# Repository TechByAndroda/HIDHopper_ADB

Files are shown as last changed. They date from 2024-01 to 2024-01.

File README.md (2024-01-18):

# HIDHopper ADB

HIDHopper ADB is a modified (forked) version of adbuino and QuokkADB.  It is a Raspberry Pi Pico based hardware device which converts USB keyboard and mouse inputs to the Apple Desktop Bus (ADB) standard.

# The Name
HIDHopper comes from the USB "HID" standard, for Human Interface Device.  Hopper just sounded right after HID.

# Picture
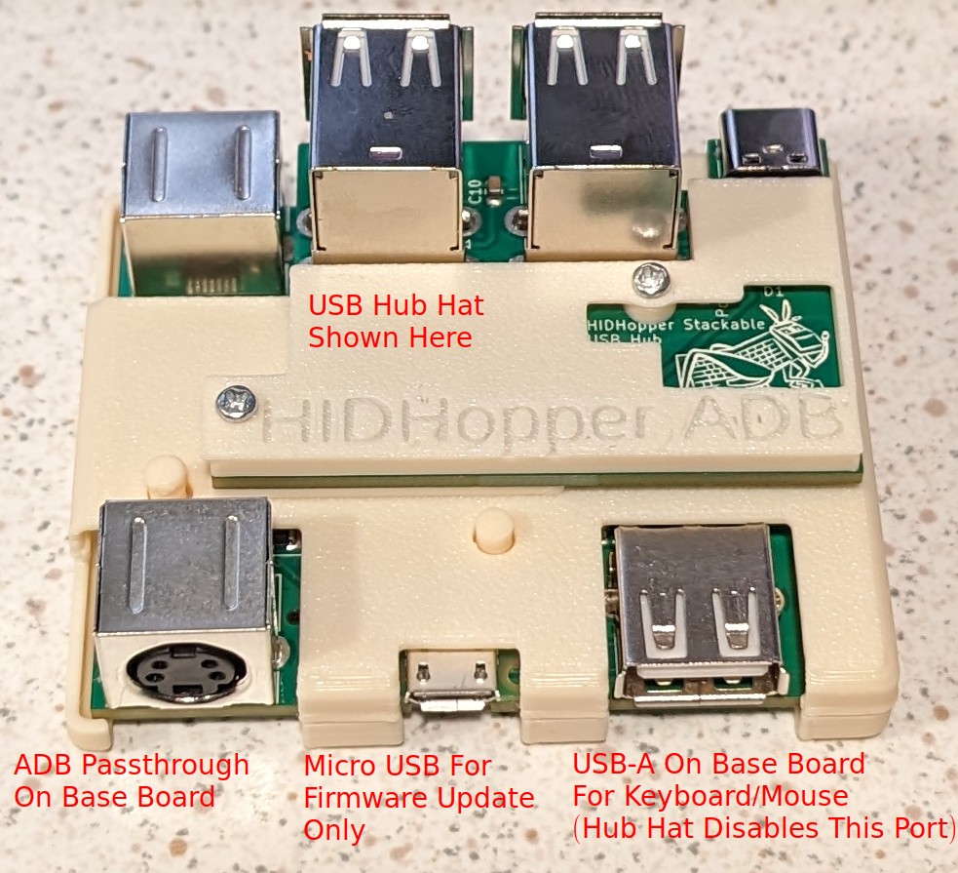
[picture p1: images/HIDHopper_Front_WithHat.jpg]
HIDHopper_ADB Hardware Image


# Usage
See the file [doc/HIDHopper.md](https://github.com/TechByAndroda/HIDHopper_ADB/blob/master/doc/HIDHopper.md) for more full documentation

# Quick Usage
- For Base HIDHopper without USB Hub, *before* turning on your computer:
   - Plug in your desired USB peripheral (keyboard or mouse)
   - Plug HIDHopper into the ADB bus
   - Start computer
   - Hot-plug *is not supported*, don't unplug from the ADB Bus *or* unplug the USB device that is connected while the computer is on
- For HIDHopper with the USB Hub Hat, *before* turning on your computer:
   - Ensure the Hub is solidly secured in place with the two mounting screws and top cover plate
   - Plug HIDHopper into the ADB bus
   - Plug in your external 5v USB-C power supply to the connector on the Hub
      - You *must use USB-C External Power* to avoid blowing the ADB Power fuse on your motherboard!
   - Plug in your desired USB keyboard and mouse
   - Hot-plug *is not supported*, don't unplug from the ADB Bus *or* unplug USB devices that are connected while the computer is on
      - Hot-plug of USB devices is finicky, sometimes it works and other times it does not
      - Best to connect before startup, that always works

# Background

This is a fork of Difegue's version of the [adbuino](https://github.com/Difegue/Chaotic-Realm), which was a modified version of [bbraun's](http://synack.net/svn/adbduino/) PS/2 to ADB arduino sketch, with some extra code added to alleviate issues with his own PS/2 keyboard.  For Difegue's original write-up, please read more info [here.](https://tvc-16.science/adbuino-ps2.html).

# How to build and flash HIDHopper ADB

Note: This software is intended to be compiled in an Ubuntu Linux environment.

- Install the Raspberry Pi Pico SDK (https://github.com/raspberrypi/pico-sdk)
- Set the `$PICO_SDK_PATH` environment variable to your pico-sdk directory
- Open a Terminal and "cd" into this project
- From the top level of this project, "cd" to the `src/firmware` folder
- In Terminal, execute the following commands from the above `src/firmware` folder:
  - `mkdir build`
  - `cd build`
  - `cmake ..`
  - `make`
- The build outputs (.uf2, .bin, .elf, etc) will be placed in this folder (path is from the top level of the project):
  - `src/firmware/build/src`
- Next, plug the micro-USB side of a USB cable into HIDHopper
- Press the button which is near the micro-USB port
- While holding down the button, plug the USB cable into your computer (then release the button after plugging in)
- You should see an "RPI-RP2" mass storage device appear on your computer
- Drag the ".uf2" file onto that mass storage device
- Once the mass storage device disappears, wait 10 seconds and then you are free to unplug

# References
ADB Pinout

## Protocol/Software Documentation
- [Apple ADB Manager Documenation](https://developer.apple.com/library/archive/documentation/mac/pdf/Devices/ADB_Manager.pdf)
- [ADB Overview](https://www.lopaciuk.eu/2021/03/26/apple-adb-protocol.html)
- [Microchip Application Note AN591](http://www.t-es-t.hu/download/microchip/an591b.pdf)
- [TMK Documentation](https://github.com/tmk/tmk_keyboard/wiki/Apple-Desktop-Bus)

## Other libraries
- [TinyUSB Library](https://github.com/raspberrypi/tinyusb)
- [MiSTER adb hardware emulation](https://github.com/mist-devel/plus_too/blob/master/adb.v)

## Development resources
- [Running OpenOCD without root](https://forgge.github.io/theCore/guides/running-openocd-without-sudo.html)

## Hardware Links
- [ADB Connector - mouser](https://www.mouser.com/ProductDetail/TE-Connectivity/5749181-1?qs=XlZqES4cpWbRcAMR%2FcJqkQ%3D%3D)

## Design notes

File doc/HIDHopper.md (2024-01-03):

# HIDHopper
A fork of adbuino / QuokkADB, HIDHopper ADB is a USB keyboard and mouse translator which converts USB signaling to Apple's vintage ADB standard.
This is for USB to ADB, and not currently the other way around.

## How to use
1. Attach any USB keyboards/mice to your HIDHopper ADB hardware
   * If you have the USB Hub Hat, EXTERNAL POWER MUST BE PROVIDED via the USB-C port!  Otherwise you run the risk of burning out the ADB Power fuse on your Mac's motherboard!
   * If you have the USB Hub Hat, only the Hat's USB ports work.  The USB port on the base device (by microUSB) will stop working to handle the hub connection.
   * The Hub Hat's USB-C Power must be un-plugged and plugged back in between each system start.  This is because certain parameters are set only on first ADB communication.
2. Ensure your HIDHopper device is plugged into your Mac before turning the computer on, and do not un-plug it (or plug it back in) while the system is running
3. The button by the ADB port on HIDHopper is the ADB Soft-Power button and can turn on systems which support that (Color Classic, PowerMac 7300, etc)
   * Systems which do not support ADB Soft-Power must be turned on with their respective physical switch
4. LEDs will turn on and blink with power and ADB activity
5. Again, DO NOT unplug HIDHopper from your Mac while it is turned on.  And DO NOT plug it into your Mac while it's turned on.  Only connect or disconnect while your Mac is turned off.

# Hardware

## Ports And Buttons

Every HIDHopper ADB device comes with:
* Two ADB ports, allowing daisy-chaining
* One USB-A port for keyboard/mouse (This port is disabled if you are using the Hub Hat)
* One micro-USB port (for firmware upgrades)
* One 4-pin jumper header for the USB Hub Hat
* An ADB Soft Power-on Button
* A button for use in entering Firmware Update mode

HIDHopper ADB Front Picture
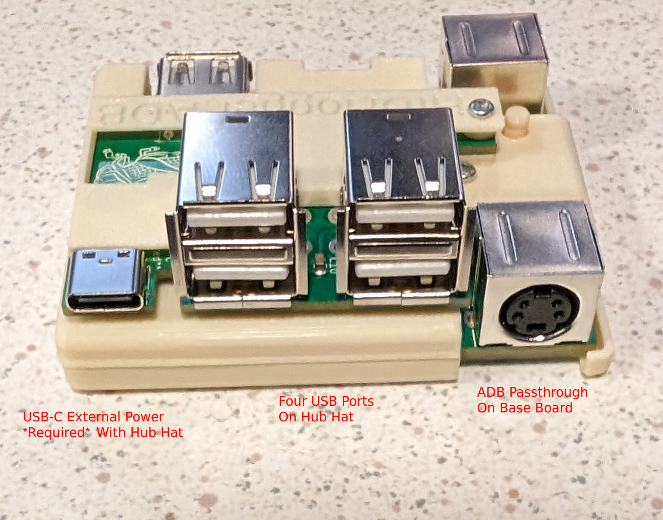
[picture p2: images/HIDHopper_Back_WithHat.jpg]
HIDHopper ADB Back Picture

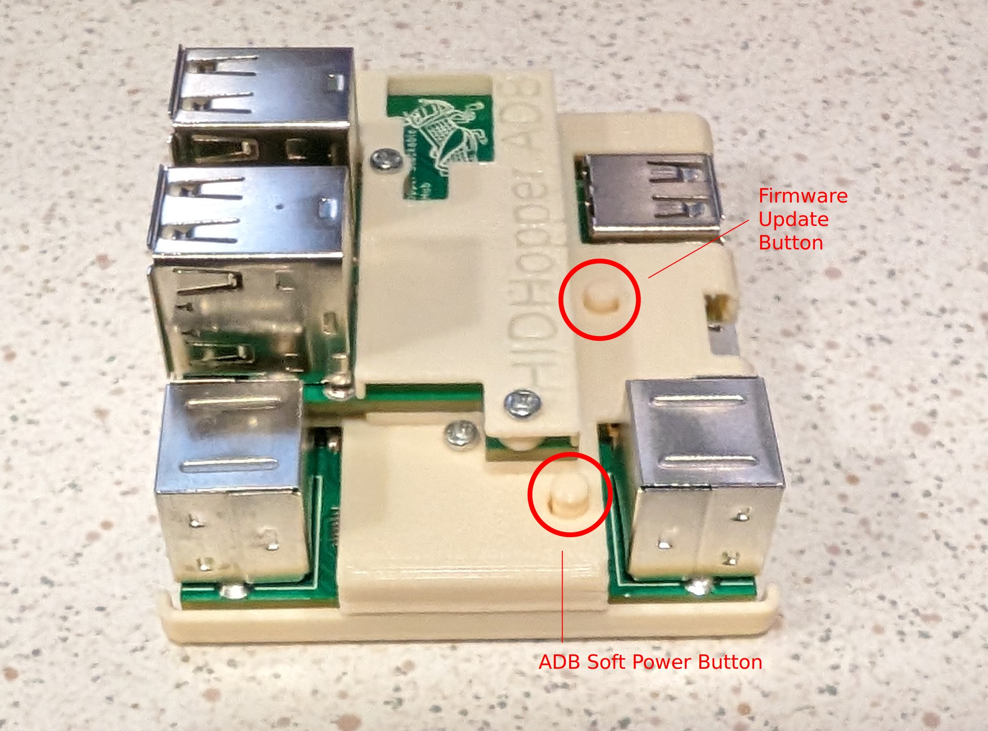
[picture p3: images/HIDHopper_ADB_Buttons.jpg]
HIDHopper ADB Back Picture


# Compatibility
HIDHopper ADB has been tested on the following systems that mouse movement and clicks work, as well as keyboard key inputs.
* Beige G3
* PowerMac 7300
* PowerBook 180
* Macintosh Portable

# Other

## Special Key-combos
The special keyboad commands start with `CTRL + SHIFT + CAPS LOCK` and a letter key.  Example: `CTRL + SHIFT + CAPS LOCK + V` ghost types the firmware version.
 - `V` - Ghost types firmware version
 - `L` - Ghost types the busy LED status (ON/OFF) and saves the new status to flash and will be used when the board powers on again. This controls
 whether the LED blinks when accessing the ADB bus or remains off for light sensitive situations.

# Firmware

## Determining Firmware Version 
The firmware version can be found by opening up an empty text document or program that allows typing. 
Press `Ctrl + Shift + CapsLock + V` and the firmware version will be ghost typed.

## Flashing Firmware Updates
1. Turn off your Mac, and un-plug HIDHopper once the system is fully off
2. Remove any USB Hub Hat which may be installed
3. Press and hold the button by the micro-USB port while plugging in a micro-USB cable to your host machine (release the button after plugging into host machine)
3a. Note that this must be a micro-USB Data Cable and not power-only
4. Download the updated firmware from the Firmware Releases section
5. Drag and drop the ".uf2" file onto the rpi-rp2 USB device which appeared after step 3
5a. rpi-rp2 is NOT actually a USB storage device, it's the Pico stick emulating a USB device for ease of firmware installation

## Current Status
 - Caps Lock with keyboard LED caps lock indicator working
 - Normal Apple mouse emulation working
 - Extended Apple US keyboard emulation working - left and right modifier keys when the OS switches keyboard type
 - Logitech Unifying receiver works
 - Scroll Lock, Pause/Break as F14, and F15 respectively 
 - Rear facing and front facing ADB can be connected to host (Mac) or another ADB device
 - Mouse and keyboard readdressing implemented so multiple HIDHopper ADB, other ADB keyboards, and/or mice can be used
 - Multiple USB keyboards or mice can be attached and will work.

## Parity with USB Wombat
 - Context menu for Mac OS 8.1 and above - middle mouse button switches right click mode
   - default: mouse right clicks are sent as Ctrl+click
   - other:  right click is sent over the ADB bus as a right click (should work on NeXTstations)
 - SysRq/Print Screen and F13 work as the Apple Power key (keycode 0x7F, separate from ADB power on button on the HIDHopper ADB)
 - Ctrl + Shift + CapsLock + V - ghost types the firmware version to the host computer
 - Power button on HIDHopper will turn on computer while HIDHopper is powered off, if the host machine supports soft power-on
  
## HIDHopper LED blink meanings
 - On boot - one blink
 - On second core and USB host driver loaded - one blink
 - On keyboard mount (connected to usb) - two blinks
 - On mouse mount (connected to usb)- three blinks
 - On device unmount (disconnected to usb) - one blink
 - Normal operation - very dim light when idle, blinks when there is activity on the ADB bus for the device.

### Normal LED sequence:
If both a mouse and keyboard are connected to the HIDHopper:

Turning on the Mac:
 1. One blink - power on
 2. One blink - second core and USB up and running
 2. Two blinks - keyboard initialized
 3. Three blinks - mouse initialized

Removing mouse:
 1. One blink

Inserting a new mouse:
 1. Three blinks

## Known Bugs
 - Repeatedly pressing buttons that toggle LED states, such as caps lock, num lock, and scroll lock results in the LEDs no longer changing state, after many LED toggles. The keyboard functions normally and functions like caps lock still works, but the LED status indicators no longer change.
 - Some USB hubs do not seem to work.

## Compiling
Pre-requisites: ARM cross compiling tools

Steps:
1. Download the pico sdk: https://github.com/raspberrypi/pico-sdk
2. set `$PICO_SDK_PATH` to that directory
3. change to the directory in this repo to `src/firmware`
4. `mkdir build`
5. `cd build`
6. `cmake ..`
7. `make`
8. .uf2, .bin, and .elf files should be in `src/firmware/build/src`

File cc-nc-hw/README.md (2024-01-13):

# HIDHopper ADB (and USB Hub Hat) PCB Design and Production Files

All files here, in and under the cc-nc-hw folder, are provided under the [Attribution-NonCommercial-ShareAlike 4.0 International License](https://creativecommons.org/licenses/by-nc-sa/4.0/deed.en)

This license was selected with the intent to allow you to produce these for personal use only, not for sale.
Please do not produce a run of these and ask to "sell the extras", those sales are in violation of the license.

Please obey the terms of this license in your usage of these files.
Any product listings for these CC-NC licensed versions will receive a notice of license infringement with expectation that the listings are taken down.

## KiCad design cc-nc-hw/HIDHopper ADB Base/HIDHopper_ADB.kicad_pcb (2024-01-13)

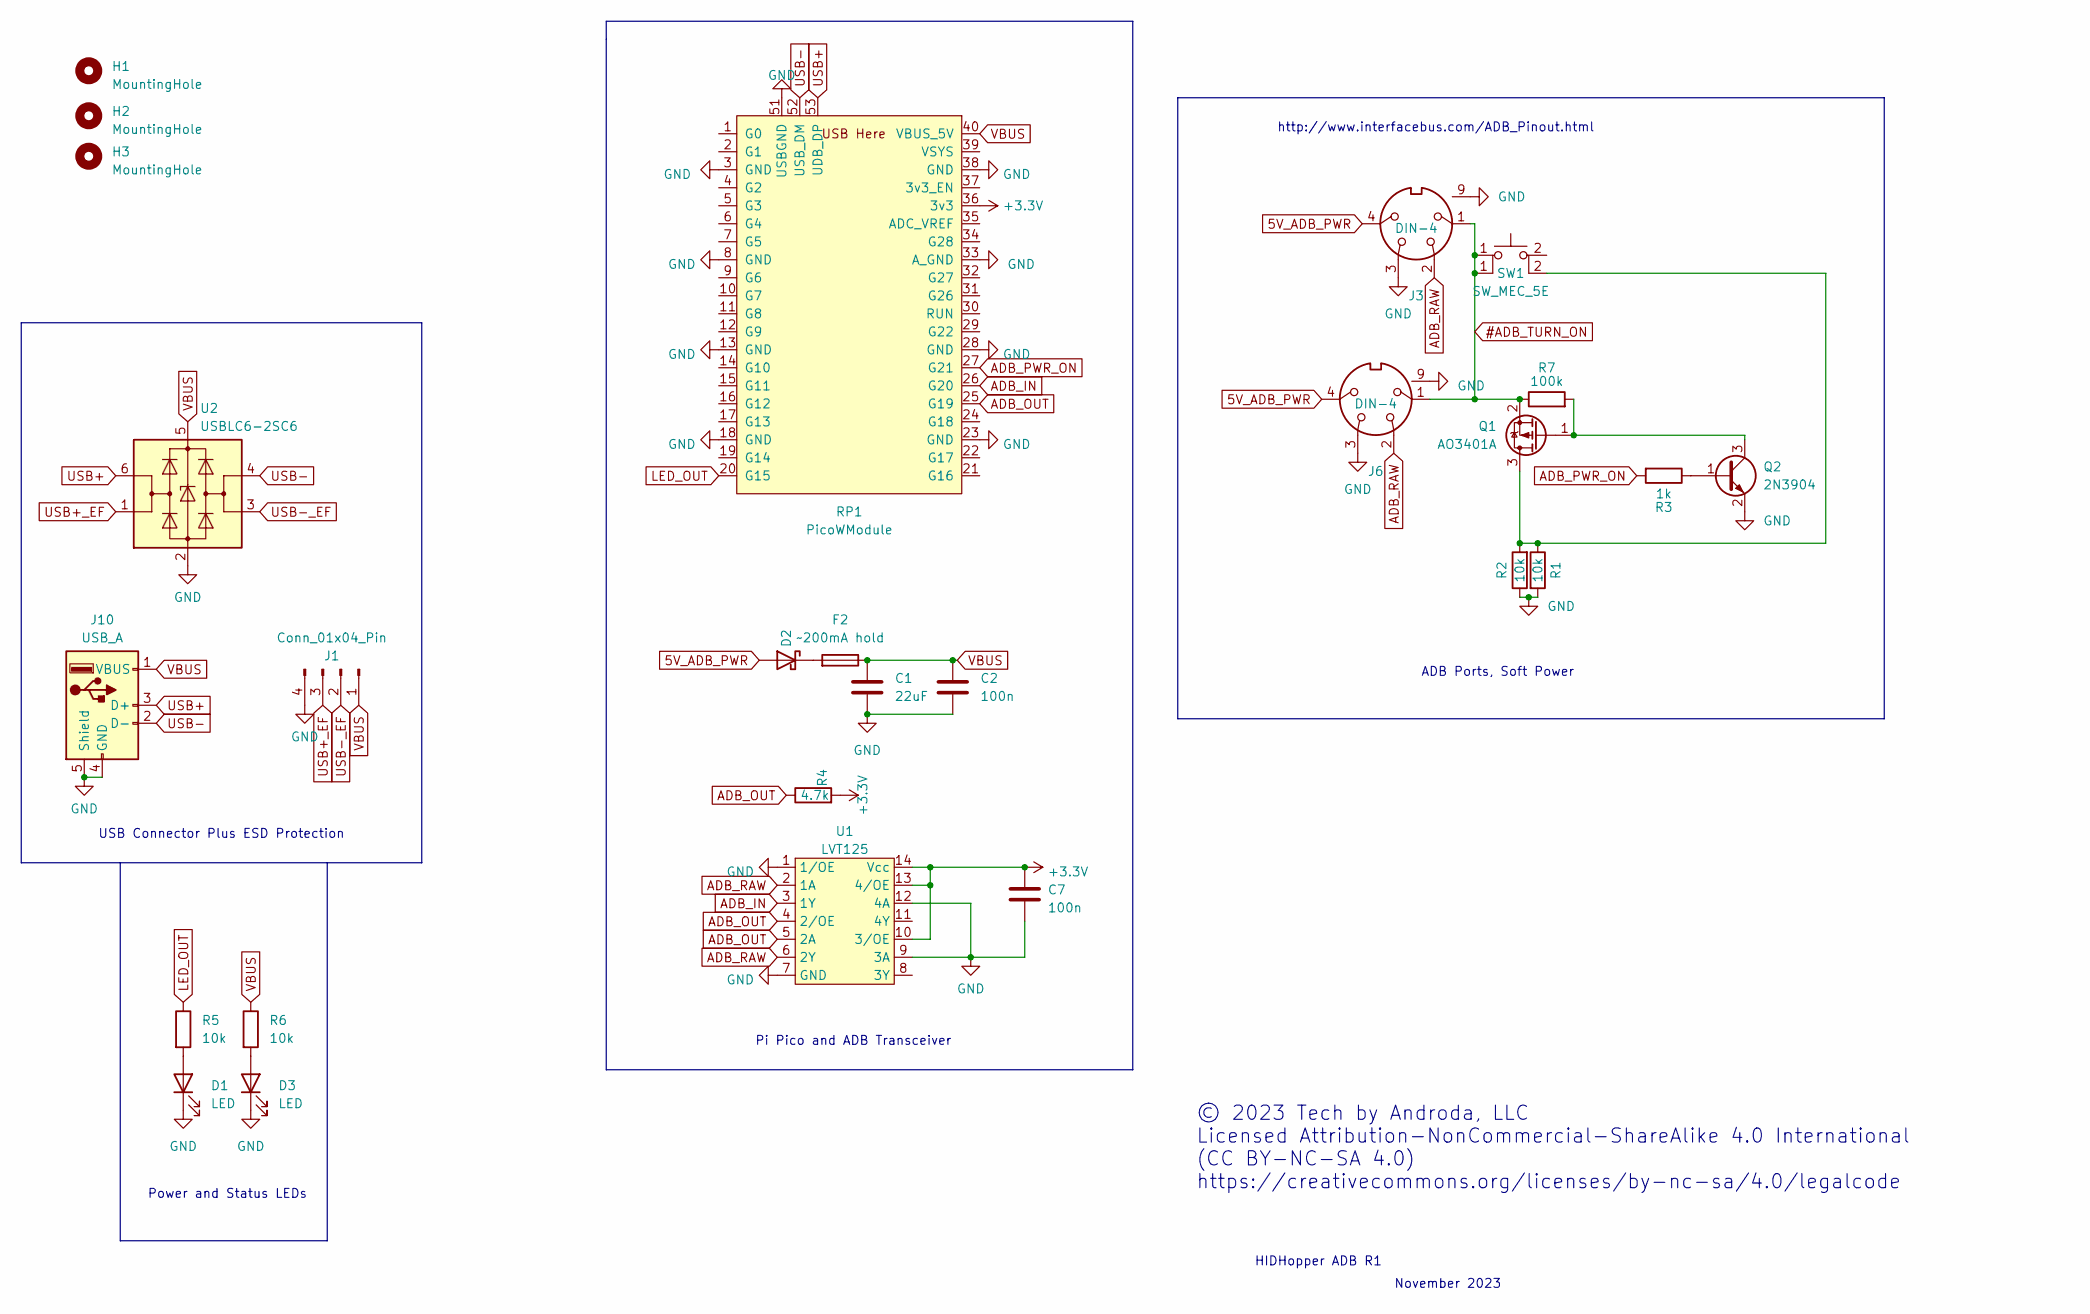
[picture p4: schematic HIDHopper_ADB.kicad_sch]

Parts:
C1: 22uF; C_1206_3216Metric
C2, C7: 100n; C_0805_2012Metric
D1, D3: LED; LED_0805_2012Metric
D2: D_Schottky; D_SMA
F2: ~200mA hold; Fuse_0603_1608Metric
H1, H2, H3: MountingHole; MountingHole_3.2mm_M3
J1: Conn_01x04_Pin; PinHeader_1x04_P2.54mm_Vertical
J3, J6: DIN-4; ADB_MDR4_MINI-DIN
J10: USB_A; USB_A_Molex_67643_Horizontal
Q1: AO3401A; SOT-23
Q2: 2N3904; SOT-23
R1, R2, R5, R6: 10k; R_0603_1608Metric
R3: 1k; R_0603_1608Metric
R4: 4.7k; R_0603_1608Metric
R7: 100k; R_0603_1608Metric
RP1: PicoWModule; Raspberry_Pi_PicoW_SMT_THT
SW1: SW_MEC_5E; TS-1187A-B-A-B
U1: LVT125; TSSOP-14_4.4x5mm_P0.65mm
U2: USBLC6-2SC6; SOT-23-6

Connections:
5V_ADB_PWR: D2.2 (A), J3.4, J6.4
#ADB_TURN_ON: J3.1, J6.1, Q1.2 (S), R7.1, SW1.1
+3.3V: C7.1, R4.2, RP1.36 (3v3), U1.10 (3/OE), U1.13 (4/OE), U1.14 (Vcc)
ADB_IN: RP1.26 (G20), U1.3 (1Y)
ADB_OUT: R4.1, RP1.25 (G19), U1.4 (2/OE), U1.5 (2A)
ADB_PWR_ON: R3.2, RP1.27 (G21)
ADB_RAW: J3.2, J6.2, U1.2 (1A), U1.6 (2Y)
GND: C1.2, C2.2, C7.2, D1.1 (K), D3.1 (K), J1.4, J3.3, J3.9, J6.3, J6.9, J10.4 (GND), J10.5 (Shield), Q2.2 (E), R1.2, R2.1, RP1.3 (GND), RP1.8 (GND), RP1.13 (GND), RP1.18 (GND), RP1.23 (GND), RP1.28 (GND), RP1.33 (A_GND), RP1.38 (GND), RP1.51 (USBGND), U1.1 (1/OE), U1.7 (GND), U1.9 (3A), U1.12 (4A), U2.2 (GND)
LED_OUT: R5.1, RP1.20 (G15)
unnamed: D1.2 (A), R5.2
unnamed: D2.1 (K), F2.2
unnamed: D3.2 (A), R6.2
unnamed: Q1.3 (D), R1.1, R2.2, SW1.2
unnamed: Q1.1 (G), Q2.3 (C), R7.2
unnamed: Q2.1 (B), R3.1
USB+: J10.3 (D+), RP1.53 (UDB_DP), U2.6 (I/O1)
USB+_EF: J1.3, U2.1 (I/O1)
USB-: J10.2 (D-), RP1.52 (USB_DM), U2.4 (I/O2)
USB-_EF: J1.2, U2.3 (I/O2)
VBUS: C1.1, C2.1, F2.1, J1.1, J10.1 (VBUS), R6.1, RP1.40 (VBUS_5V), U2.5 (VBUS)

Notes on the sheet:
Pi Pico and ADB Transceiver
HIDHopper ADB R1
ADB Ports, Soft Power
© 2023 Tech by Androda, LLC Licensed Attribution-NonCommercial-ShareAlike 4.0 International (CC BY-NC-SA 4.0) https://creativecommons.org/licenses/by-nc-sa/4.0/legalcode
November 2023
USB Connector Plus ESD Protection
http://www.interfacebus.com/ADB_Pinout.html
Power and Status LEDs

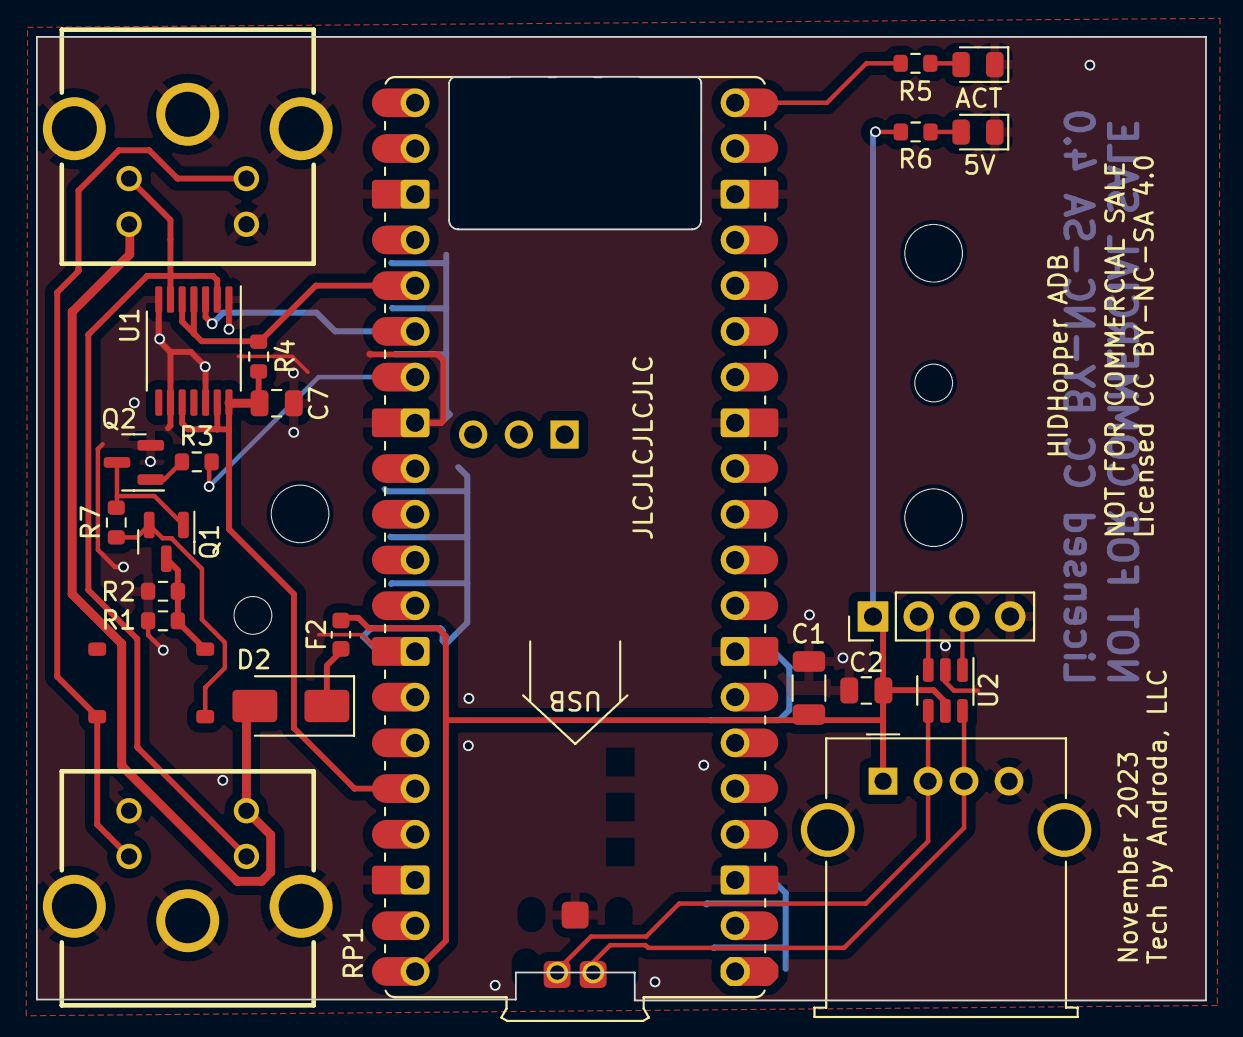
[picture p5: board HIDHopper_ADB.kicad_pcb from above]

Board: 2 copper layers, 64.9 x 53.5 mm, 27 parts (0 on the bottom side), 20 nets.

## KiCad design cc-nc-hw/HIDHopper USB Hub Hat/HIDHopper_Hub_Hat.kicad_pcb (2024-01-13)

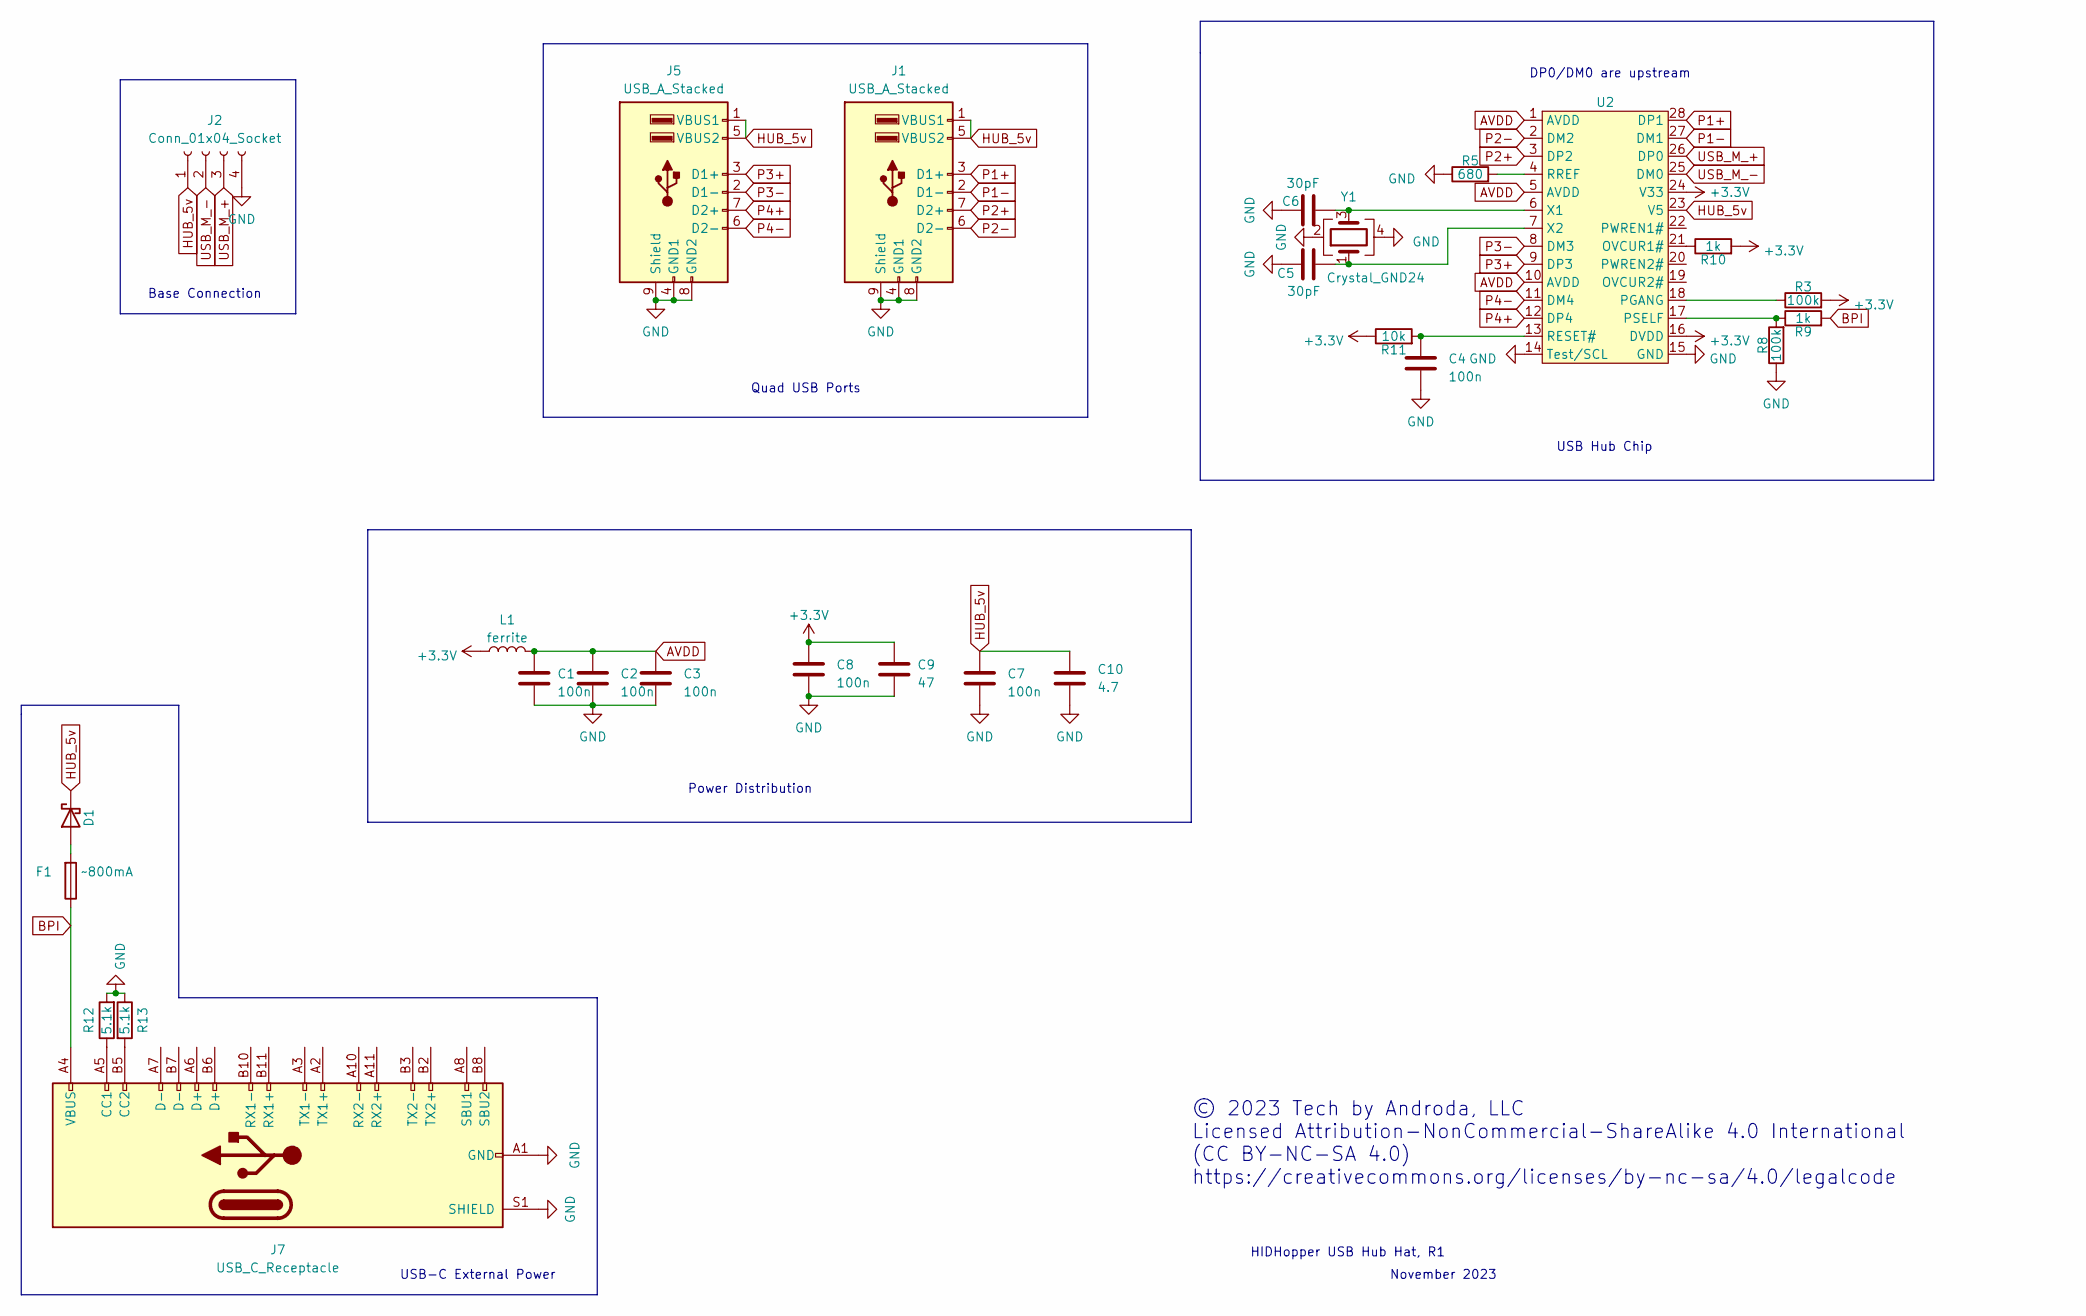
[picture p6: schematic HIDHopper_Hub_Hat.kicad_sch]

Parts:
C1, C2, C3, C7, C8: 100n; C_0805_2012Metric
C4: 100n
C5, C6: 30pF; C_0402_1005Metric
C9: 47; C_1206_3216Metric
C10: 4.7; C_0805_2012Metric
D1: D_Schottky; D_SMA
F1: ~800mA; Fuse_0805_2012Metric
J1, J5: USB_A_Stacked; USB_A_CUI_UJ2-ADH-TH_Horizontal_Stacked
J2: Conn_01x04_Socket; PinSocket_1x04_P2.54mm_Vertical
J7: USB_C_Receptacle; USB_C_Receptacle_HRO_TYPE-C-31-M-12
L1: ferrite; L_0805_2012Metric
R3, R8: 100k; R_0603_1608Metric
R5: 680; R_0603_1608Metric
R9, R10: 1k; R_0603_1608Metric
R11: 10k
R12, R13: 5.1k; R_0402_1005Metric
U2: SSOP-28_5.3x10.2mm_P0.65mm
Y1: Crystal_GND24; Crystal_SMD_3225-4Pin_3.2x2.5mm

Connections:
+3.3V: C8.1, C9.1, L1.1, R3.2, R10.2, R11.1, U2.16 (DVDD), U2.24 (V33)
AVDD: C1.1, C2.1, C3.1, L1.2, U2.1 (AVDD), U2.5 (AVDD), U2.10 (AVDD)
BPI: F1.1, J7.A4 (VBUS), J7.A9 (VBUS), J7.B4 (VBUS), J7.B9 (VBUS), R9.2
GND: C1.2, C2.2, C3.2, C4.2, C5.2, C6.2, C7.2, C8.2, C9.2, C10.2, J1.4 (GND1), J1.8 (GND2), J1.9 (Shield), J2.4, J5.4 (GND1), J5.8 (GND2), J5.9 (Shield), J7.A1 (GND), J7.A12 (GND), J7.B1 (GND), J7.B12 (GND), J7.S1 (SHIELD), R5.1, R8.1, R12.2, R13.1, U2.14 (Test/SCL), U2.15 (GND), Y1.2, Y1.4
HUB_5v: C7.1, C10.1, D1.1 (K), J1.1 (VBUS1), J1.5 (VBUS2), J2.1, J5.1 (VBUS1), J5.5 (VBUS2), U2.23 (V5)
unnamed: D1.2 (A), F1.2
unnamed: J7.A5 (CC1), R12.1
unnamed: J7.B5 (CC2), R13.2
unnamed: R10.1, U2.21 (OVCUR1#)
unnamed: R3.1, U2.18 (PGANG)
unnamed: R8.2, R9.1, U2.17 (PSELF)
unnamed: C4.1, R11.2, U2.13 (RESET#)
unnamed: R5.2, U2.4 (RREF)
unnamed: C6.1, U2.6 (X1), Y1.3
unnamed: C5.1, U2.7 (X2), Y1.1
P1+: J1.3 (D1+), U2.28 (DP1)
P1-: J1.2 (D1-), U2.27 (DM1)
P2+: J1.7 (D2+), U2.3 (DP2)
P2-: J1.6 (D2-), U2.2 (DM2)
P3+: J5.3 (D1+), U2.9 (DP3)
P3-: J5.2 (D1-), U2.8 (DM3)
P4+: J5.7 (D2+), U2.12 (DP4)
P4-: J5.6 (D2-), U2.11 (DM4)
USB_M_+: J2.3, U2.26 (DP0)
USB_M_-: J2.2, U2.25 (DM0)

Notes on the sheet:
HIDHopper USB Hub Hat, R1
USB Hub Chip
November 2023
Power Distribution
Base Connection
© 2023 Tech by Androda, LLC Licensed Attribution-NonCommercial-ShareAlike 4.0 International (CC BY-NC-SA 4.0) https://creativecommons.org/licenses/by-nc-sa/4.0/legalcode
DP0/DM0 are upstream
Quad USB Ports
USB-C External Power

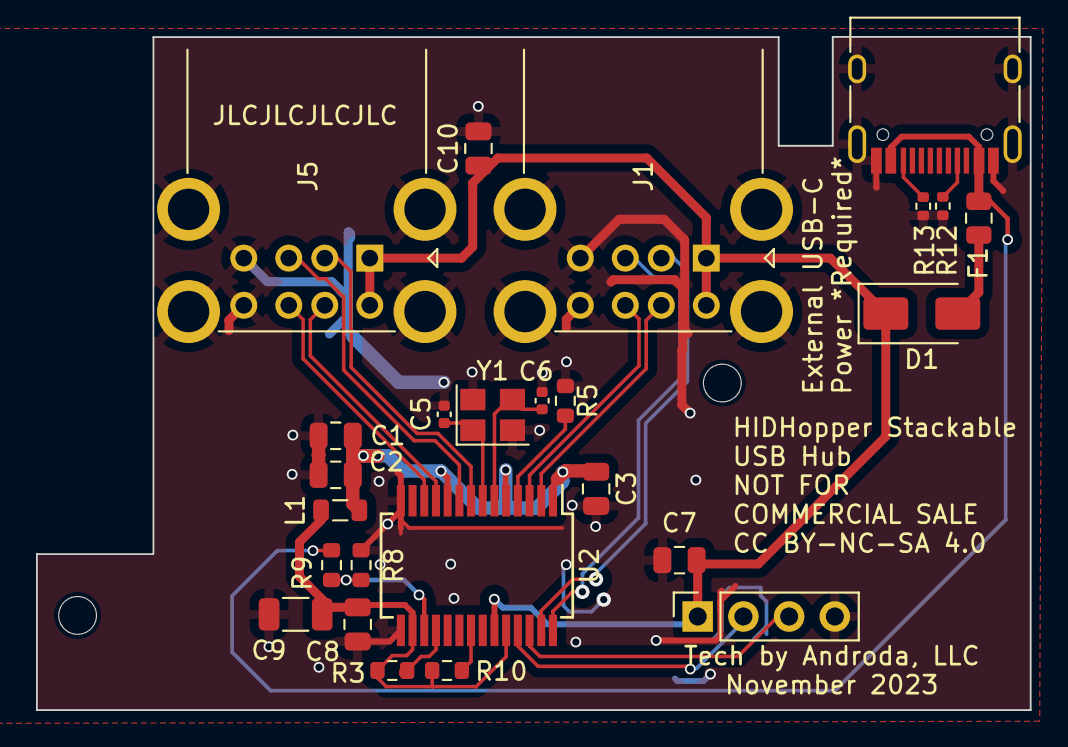
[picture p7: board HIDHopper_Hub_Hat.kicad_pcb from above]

Board: 2 copper layers, 55.2 x 37.4 mm, 25 parts (0 on the bottom side), 24 nets.

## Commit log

2024-01-01 Update HIDHopper.md
    Buttons image
2024-01-06 Updated Case Design Images
2024-01-11 Remove old hw folder, new to be added
    [BOM-adbuino.csv, LevelShifter.kicad_sch, LevelShifter.sch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]
2024-01-13 HIDHopper Base and USB Hub Hat, R1
    [HIDHopper_ADB-B_Cu.gbr, HIDHopper_ADB-B_Mask.gbr, HIDHopper_ADB-B_Paste.gbr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]
2024-01-18 Update README.md
    Case design was changed, update readme to match

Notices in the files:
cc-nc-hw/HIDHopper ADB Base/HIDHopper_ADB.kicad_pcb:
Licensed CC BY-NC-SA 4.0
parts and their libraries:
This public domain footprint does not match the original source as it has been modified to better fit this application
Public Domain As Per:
